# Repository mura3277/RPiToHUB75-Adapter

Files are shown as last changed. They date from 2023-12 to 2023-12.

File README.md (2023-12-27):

# Raspberry Pi 40 Pin GPIO to HUB75 Adapter Board

This PCB maps the Pi GPIO to the HUB75 header. The remaining pins are mapped to a 8-pin header to connect additional devices. It is intended this is used with the [RGB LED Matrix](https://github.com/hzeller/rpi-rgb-led-matrix/tree/master) library.

Pin mapping for the remaining pins from the Pi GPIO:
|Col 1 | Col 2 |
|---|---|
|GPIO 6 |GPIO 13 |
|5v Power  |GPIO 19 |
|GND |GPIO 26 |

Pin mapping for IO header for the future input PCB:
|Col 1 | Col 2 |
|---|---|
|GPIO 12 |GPIO 1 |
|GPIO 20 |GPIO 16 |
|GND |GPIO 21 |

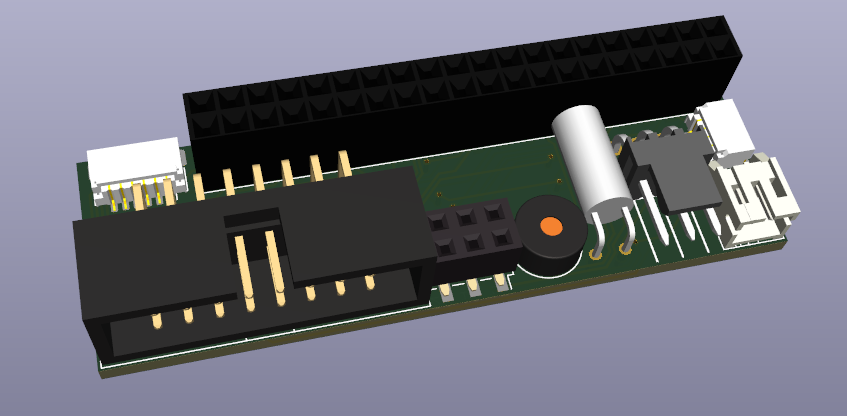
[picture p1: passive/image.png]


# Change Log
## 7.0
-  Added 2 pin power header.
-  Added 4 pin STEMMA QT connector.
-  Changed the 6 pin IO to a smaller JST SH.
-  Changed the 6 pin GPIO to a low profile pin socket.
-  Adjusted layout to support RPi5 with 5-6mm heatsink

## 6.0
-  Went back to the regular HUB75 mapping as outlined by the rpi-rgb-led-matrix repo.
-  Dropped some pins from the GPIO passthrough (extra GND, 3.3v).

## 5.0
-  Added a right angled tilt sensor to the board, connected to a GPIO pin.

## 4.0
-  Added buzzer to the board connected to a GPIO pin.
-  Split off the dedicated input pins to a 6 pin IDC so it can easily be connected to a daughter board.

## 3.0
-  Added 3 pin fan header connected to a GPIO pin for cooling a pi within an enclosure.

## 2.0
-  Added solder jumper pads to support displays with or without the extra data line E.

## 1.0
- Initial Version.

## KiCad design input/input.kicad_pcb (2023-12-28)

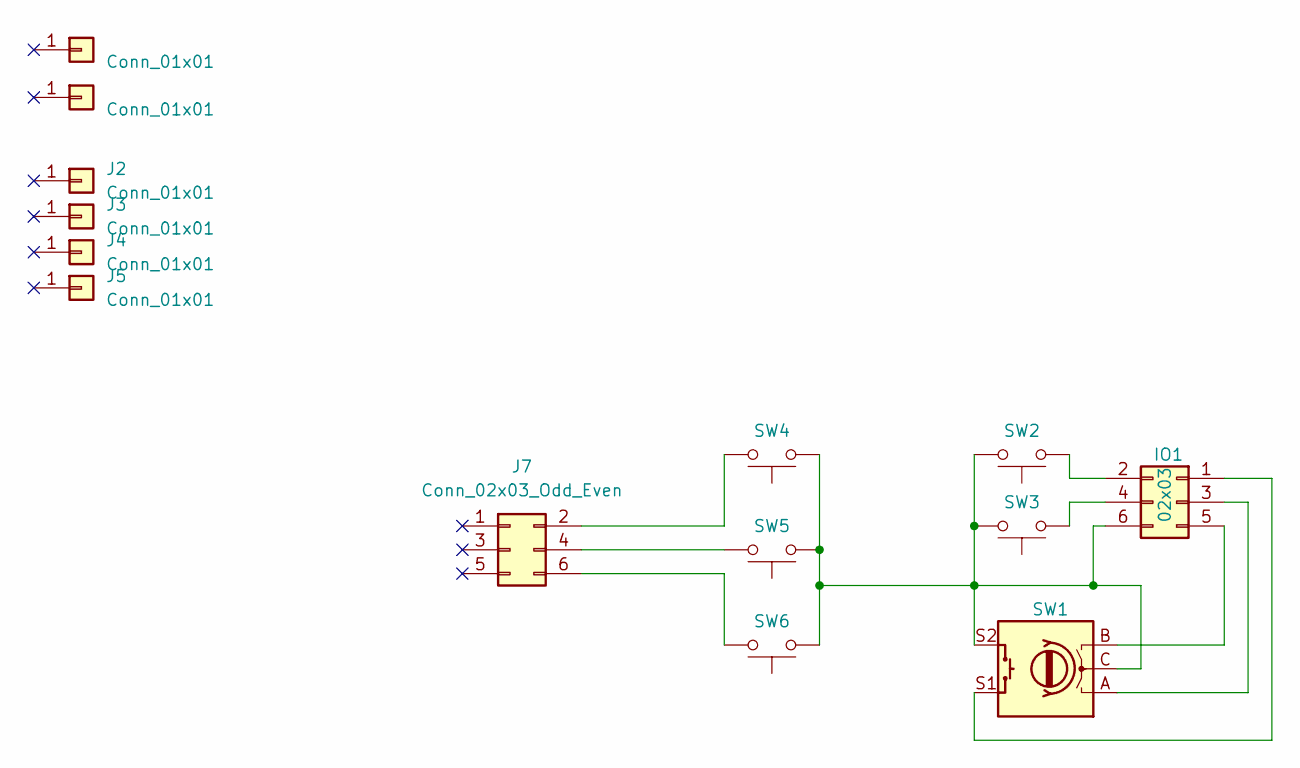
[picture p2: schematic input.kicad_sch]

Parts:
IO1: 02x03; JST_SH_SM06B-SRSS-TB_1x06-1MP_P1.00mm_Horizontal
J1: Conn_01x01; Breadboard
J2, J3, J4, J5: Conn_01x01; PinHeader_1x01_P2.54mm_Vertical
J6: Conn_01x01; raspberrypi_2_3
J7: Conn_02x03_Odd_Even; PinSocket_2x03_P2.54mm_Vertical
SW1: RotaryEncoder_Switch; RotaryEncoder_Alps_EC11E-Switch_Vertical_H20mm
SW2, SW3, SW4, SW5, SW6: SW_Push; SW_PUSH-12mm

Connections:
unnamed: IO1.1, SW1.S1
unnamed: IO1.2, SW2.1
unnamed: IO1.3, SW1.A
unnamed: IO1.4, SW3.1
unnamed: IO1.5, SW1.B
unnamed: IO1.6, SW1.C, SW1.S2, SW2.2, SW3.2, SW4.1, SW5.1, SW6.1
unnamed: J7.2, SW4.2
unnamed: J7.4, SW5.2
unnamed: J7.6, SW6.2

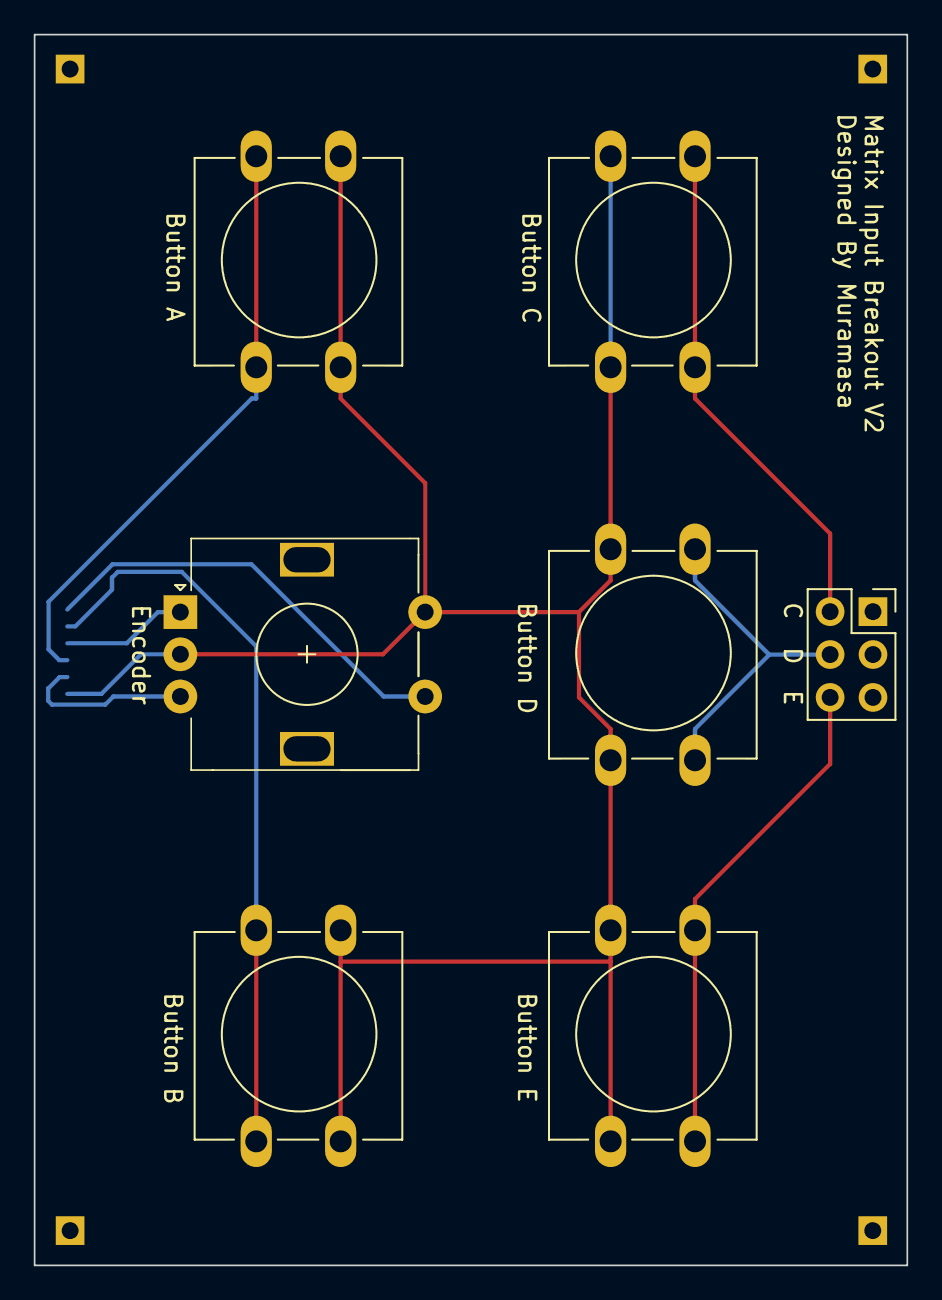
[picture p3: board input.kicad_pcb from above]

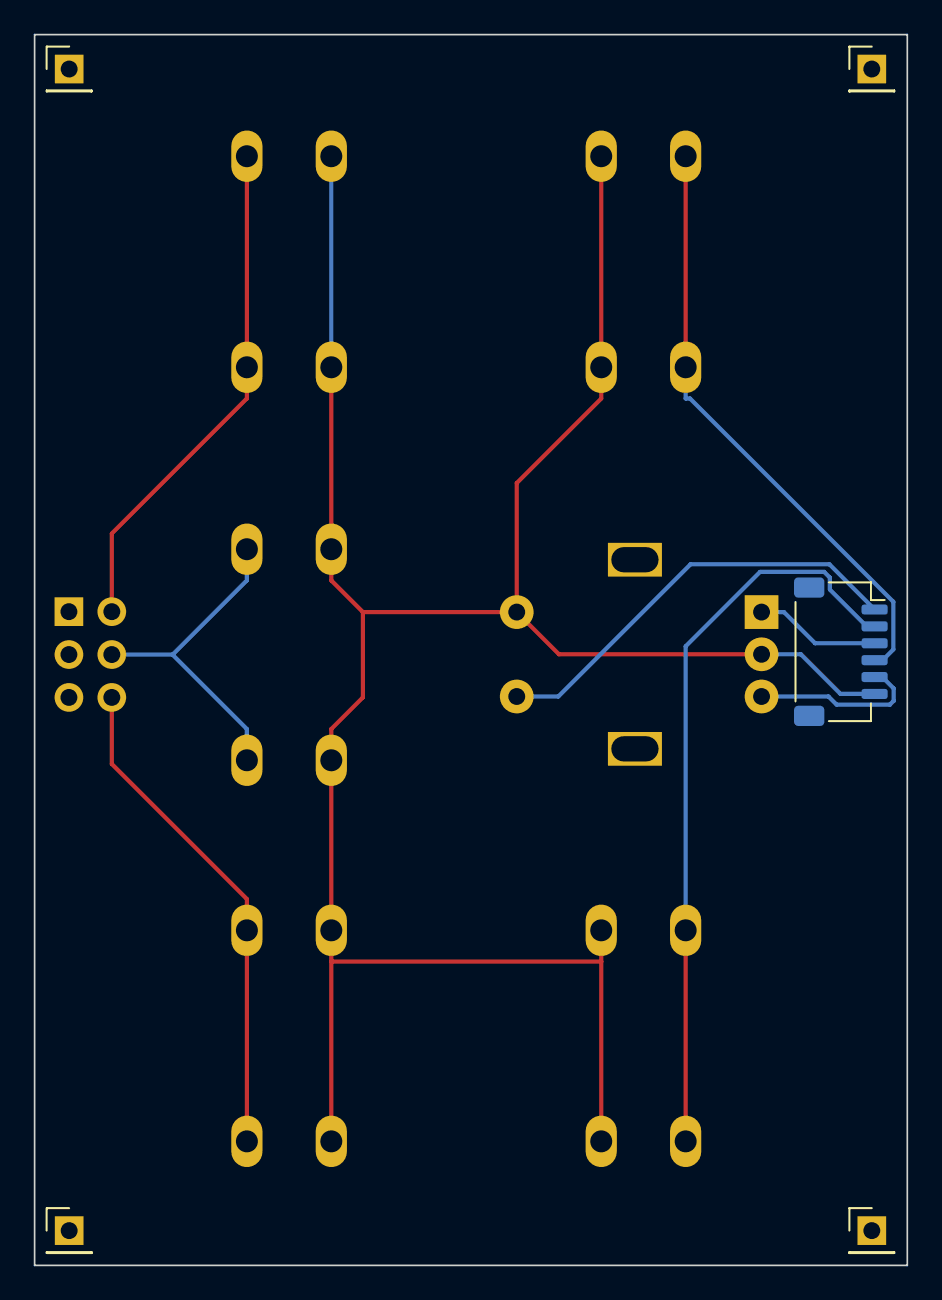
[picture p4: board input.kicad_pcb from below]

Board: 2 copper layers, 51.7 x 72.9 mm, 14 parts (6 on the bottom side), 9 nets.

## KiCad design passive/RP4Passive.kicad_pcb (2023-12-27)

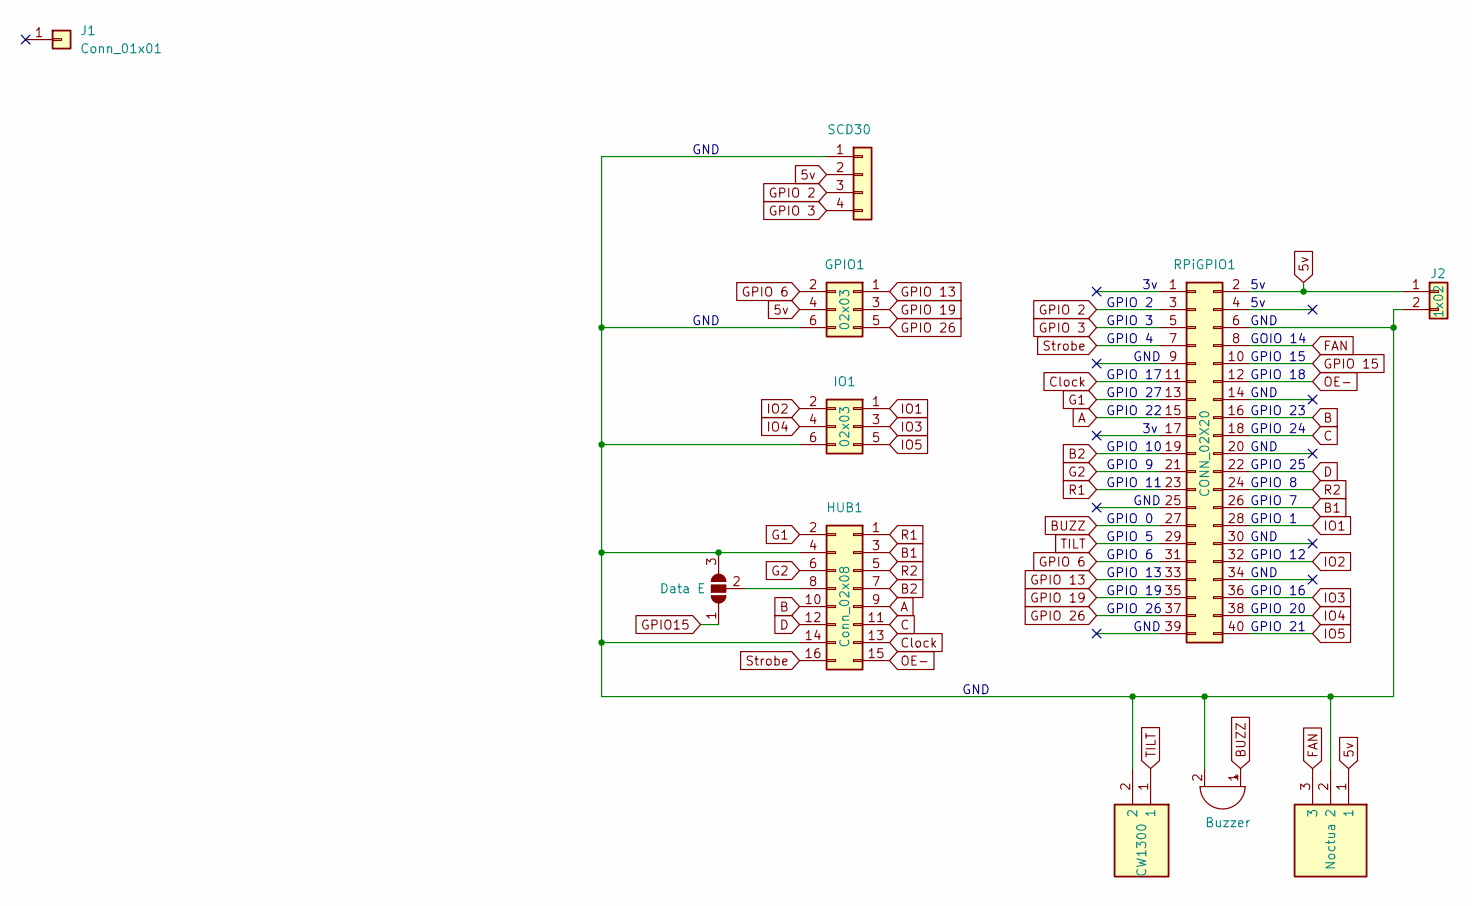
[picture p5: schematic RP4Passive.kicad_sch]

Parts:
BZ1: Buzzer; MagneticBuzzer_Kingstate_KCG0601
GPIO1: 02x03; GPIO Header
HUB1: Conn_02x08; HUB75
IO1: 02x03; JST_SH_SM06B-SRSS-TB_1x06-1MP_P1.00mm_Horizontal
J1: Conn_01x01; raspberrypi_2_3
J2: 1x02; JST_PH_S2B-PH-K_1x02_P2.00mm_Horizontal
JP1: Data E; SolderJumper-3_P1.3mm_Open_Pad1.0x1.5mm_NumberLabels
M1: Noctua; HDRRA3W64P0X254_1X3_747X318X635P; Mouser Part Number 538-171857-3003
RPiGPIO1: CONN_02X20; RPi GPIO
S1: CW1300; CW13001; Manufacturer_Part_Number CW1300-1
SCD30: Conn_01x04_Socket; STEMMA QT 1x04

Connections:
5v: GPIO1.4, J2.1, M1.1, RPiGPIO1.2, SCD30.2
A: HUB1.9, RPiGPIO1.15
B: HUB1.10, RPiGPIO1.16
B1: HUB1.3, RPiGPIO1.26
B2: HUB1.7, RPiGPIO1.19
BUZZ: BZ1.1 (-), RPiGPIO1.27
C: HUB1.11, RPiGPIO1.18
Clock: HUB1.13, RPiGPIO1.11
D: HUB1.12, RPiGPIO1.22
FAN: M1.3, RPiGPIO1.8
G1: HUB1.2, RPiGPIO1.13
G2: HUB1.6, RPiGPIO1.21
GPIO15: JP1.1 (A)
GPIO 2: RPiGPIO1.3, SCD30.3
GPIO 3: RPiGPIO1.5, SCD30.4
GPIO 6: GPIO1.2, RPiGPIO1.31
GPIO 13: GPIO1.1, RPiGPIO1.33
GPIO 15: RPiGPIO1.10
GPIO 19: GPIO1.3, RPiGPIO1.35
GPIO 26: GPIO1.5, RPiGPIO1.37
IO1: IO1.1, RPiGPIO1.28
IO2: IO1.2, RPiGPIO1.32
IO3: IO1.3, RPiGPIO1.36
IO4: IO1.4, RPiGPIO1.38
IO5: IO1.5, RPiGPIO1.40
unnamed: BZ1.2 (+), GPIO1.6, HUB1.4, HUB1.14, IO1.6, J2.2, JP1.3 (B), M1.2, RPiGPIO1.6, S1.2, SCD30.1
unnamed: HUB1.8, JP1.2 (C)
OE-: HUB1.15, RPiGPIO1.12
R1: HUB1.1, RPiGPIO1.23
R2: HUB1.5, RPiGPIO1.24
Strobe: HUB1.16, RPiGPIO1.7
TILT: RPiGPIO1.29, S1.1

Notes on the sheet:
GND
GPIO 22
GPIO 7
GPIO 12
GPIO 8
GPIO 16
GPIO 5
GPIO 23
GPIO 2
GPIO 11
GPIO 10
GPIO 27
GPIO 0
GPIO 4
GPIO 3
GND
GPIO 13
GOIO 14
GPIO 1
GPIO 21
GPIO 9
GPIO 26
GPIO 17
GPIO 24
GPIO 15
GPIO 18
GPIO 6
GPIO 19
GPIO 20
GPIO 25

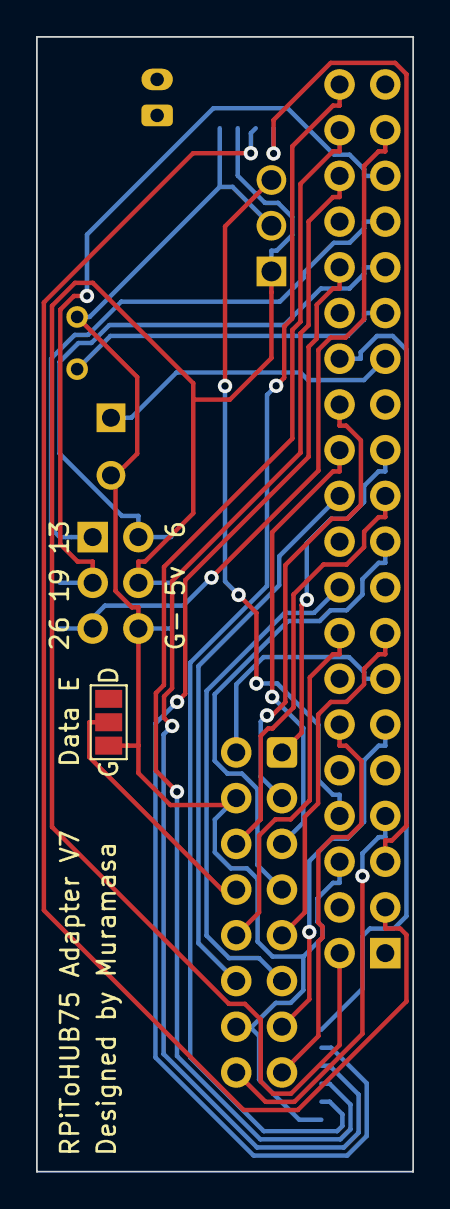
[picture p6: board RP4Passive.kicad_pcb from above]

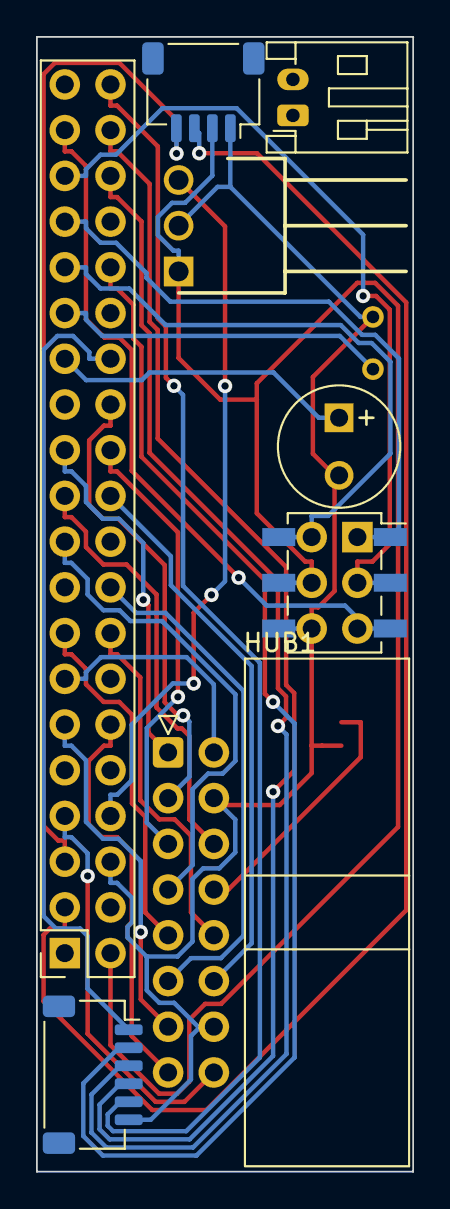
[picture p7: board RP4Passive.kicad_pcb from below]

Board: 2 copper layers, 20.9 x 63.0 mm, 11 parts (10 on the bottom side), 30 nets.

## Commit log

2023-12-24 add files for version 1
    [GPIO2HUB75-B_Cu.gbr, GPIO2HUB75-B_Mask.gbr, GPIO2HUB75-B_Paste.gbr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]
2023-12-25 added solder bridge to support 64x64+ panels
    [GPIO2HUB75.kicad_pcb, GPIO2HUB75.kicad_sch]
2023-12-25 added a 3pin fan header
    [GPIO2HUB75.kicad_pcb, GPIO2HUB75.kicad_sch]
2023-12-25 added a buzzer and split input pins from general GPIO
    [GPIO2HUB75.kicad_pcb, GPIO2HUB75.kicad_sch]
2023-12-26 added tilt sensor
    [GPIO2HUB75.kicad_pcb, GPIO2HUB75.kicad_sch]
2023-12-26 version 5
    [GPIO2HUB75.kicad_pcb]
2023-12-26 folder restructure
    [GPIO2HUB75-B_Cu.gbr, GPIO2HUB75-B_Mask.gbr, GPIO2HUB75-B_Paste.gbr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]
2023-12-26 update readme to version 6
    [RP4Passive.kicad_pcb]
2023-12-26 update pin mapping to reflect rewire
2023-12-26 add back 3.3v for the future co2 sensor
    [RP4Passive.kicad_pcb, RP4Passive.kicad_sch]
2023-12-27 version 7
    [RP4Passive.kicad_pcb, RP4Passive.kicad_sch]
2023-12-27 update image
    [RP4Passive.kicad_pcb]
2023-12-28 add input pcb breakout
    [input.kicad_pcb, input.kicad_sch]
